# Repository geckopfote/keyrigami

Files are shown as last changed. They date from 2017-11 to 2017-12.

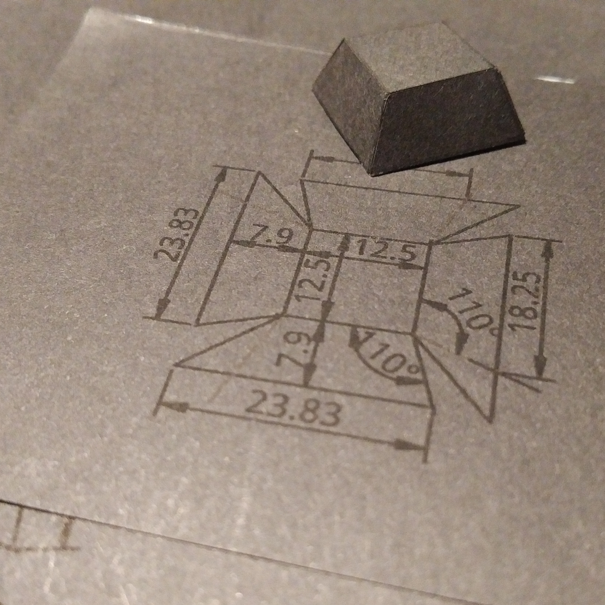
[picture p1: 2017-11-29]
showcase/IMG_20171022_220719_898.jpg

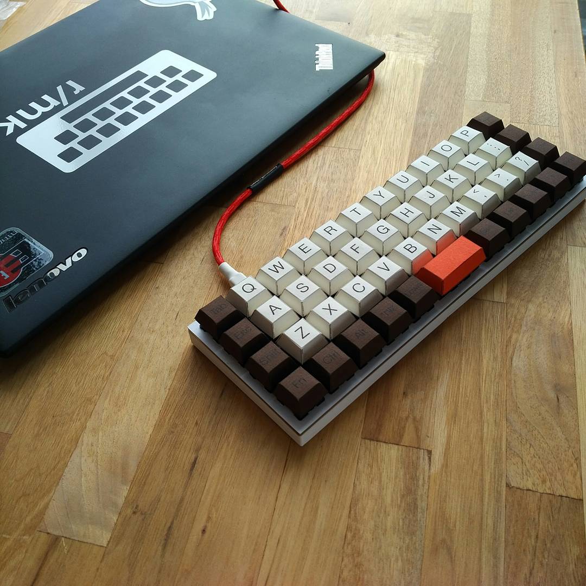
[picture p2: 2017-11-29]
showcase/IMG_20171126_132849_900.jpg

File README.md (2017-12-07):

# keyrigami

Keycaps made from paper

## Table of Contents

1. Keyrigami? What are you talking about?
2. Before you start, or: what you need to make your own paperkeycaps
3. Where to start
4. Credits
5. Links
---

### 1. Keyrigami? What the ...?
Keyrigami is a neologism out of Key(caps) and [Kirigami][1], a variation of Origami. The word keyrigami was first mentioned by u/impudentmortal on [Reddit][2], where I had posted a [picture](../master/showcase/IMG_20171126_0948504.jpg) of my [Origamikeyboard][3].

### 2. Before you start 
You will need only a few things to build your own set of paperkeycaps. First of all you need paper. A weight of 120g-300g should work. Next you need a printer to print the templates of the keycaps and you need also a 3D printer to 3D print the stems of the keycaps. Or at least you should know someone who has a 3D printer and owes you a favor. Furthermore you will need some ordinary office stuff, like glue, scissors and so on. In the wiki, I'll go into details. 

### 3. Where to start
Have a look at the [dsa_family/cad](../master/dsa_family/cad) folder, there are the original keyrigami files from my Origamikeyboard.

### 4. Credits

### 5. Links
- OLKB Keyboards https://olkb.com
- QMK Firmware http://qmk.fm/

---

[1]: https://en.wikipedia.org/wiki/kirigami
[2]: https://www.reddit.com/r/MechanicalKeyboards/comments/7fm4t6/origamikeyboard/dqdek10/
[3]: https://www.reddit.com/r/MechanicalKeyboards/comments/7fm4t6/origamikeyboard/
[4]: https://olkb.com
[5]: http://qmk.fm/

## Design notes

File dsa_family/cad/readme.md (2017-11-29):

This folder contains the different CAD files. I'm using QCad (3.17.3) for the paperkeycaps and FreeCAD (0.17) for the 3D printed parts. Both of them are OpenSource and cross platform. The .dxf-files can also be opened with Inkscape, but it's neither tested nor is it ideal, because the importprocess isn't perfect.

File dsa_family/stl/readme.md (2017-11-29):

This folder contains the .stl file(s), ready for the slicer of your choice. The keybases with a (-)*x*deg in it's filename have a slightly rotated stem, to compensate not straight built-in switches.

---

My slicer settings:

* 3D Printer: Anet A8 Prusa i3
* Slicer Software: Slic3r Prusa Edition

* 0.2mm Nozzle
* Layer Height 0.12mm
* Infill 10%
* Perimeters 1

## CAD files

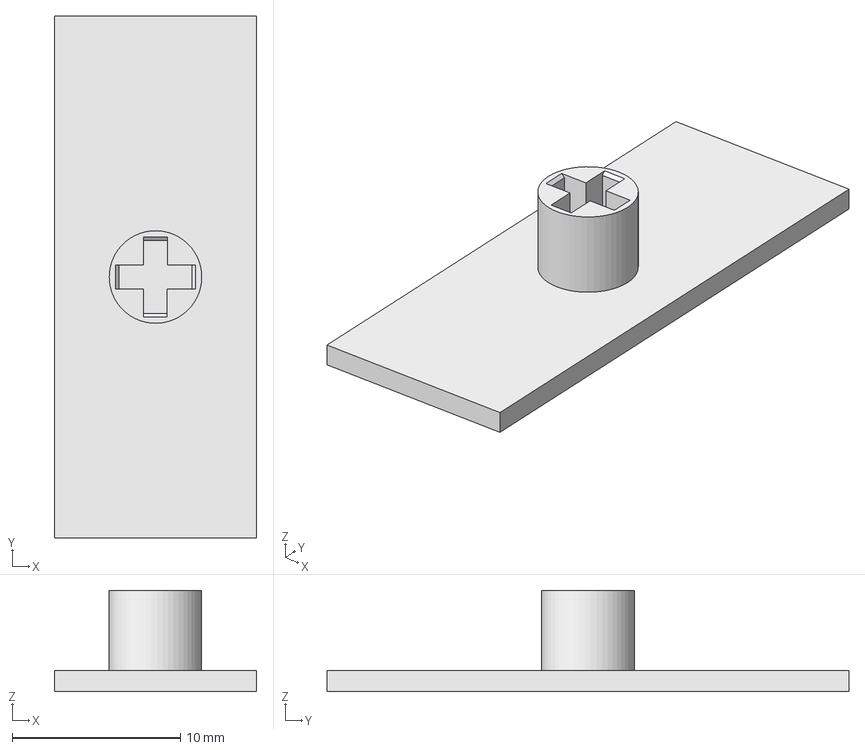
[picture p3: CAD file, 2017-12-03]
dsa_family/cad/okb_keybase_2U_6mm_new.fcstd
12.0 x 31.0 x 6.00 mm

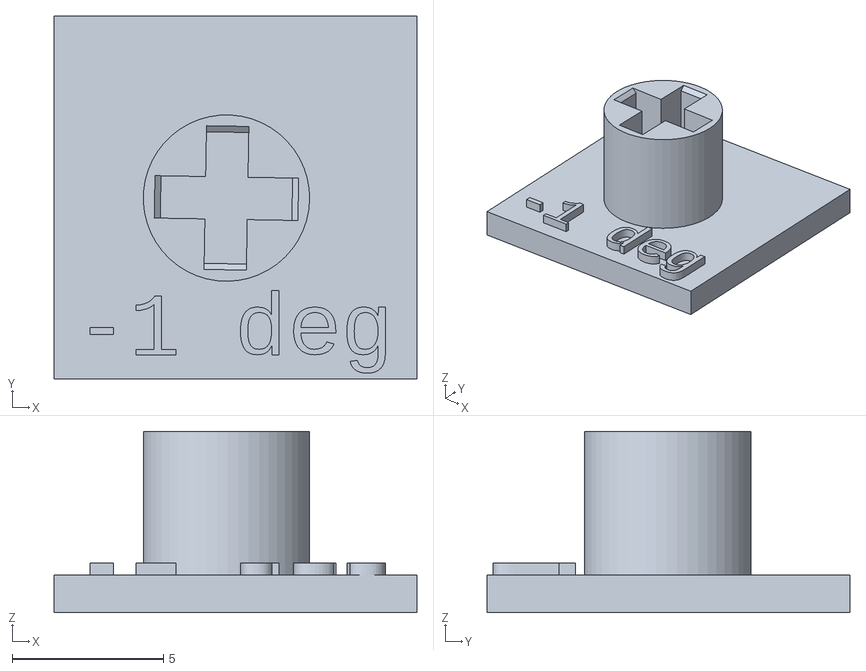
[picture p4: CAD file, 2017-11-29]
dsa_family/stl/okb_keybase_6mm_-1deg.stl
12.0 x 12.0 x 6.00

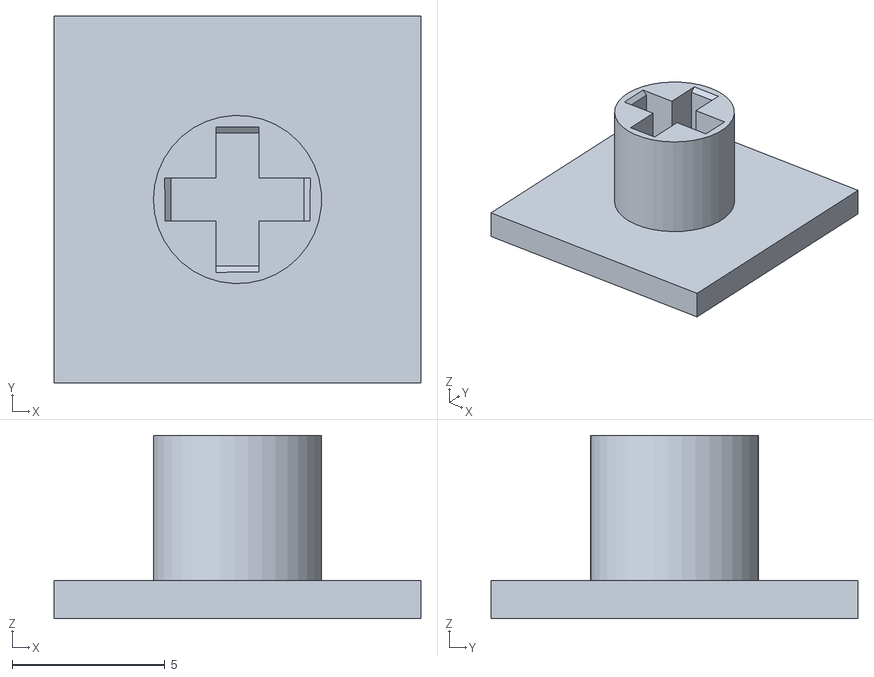
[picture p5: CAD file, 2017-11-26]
dsa_family/stl/okb_keybase_6mm.stl
12.0 x 12.0 x 6.00

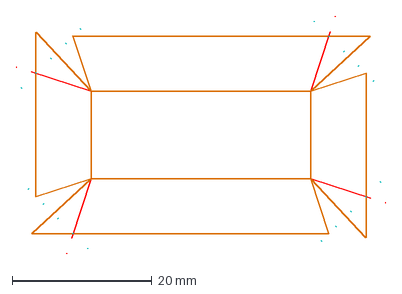
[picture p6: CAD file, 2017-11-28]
dsa_family/cad/keycap2U_single.dxf
53.0 x 34.0 mm

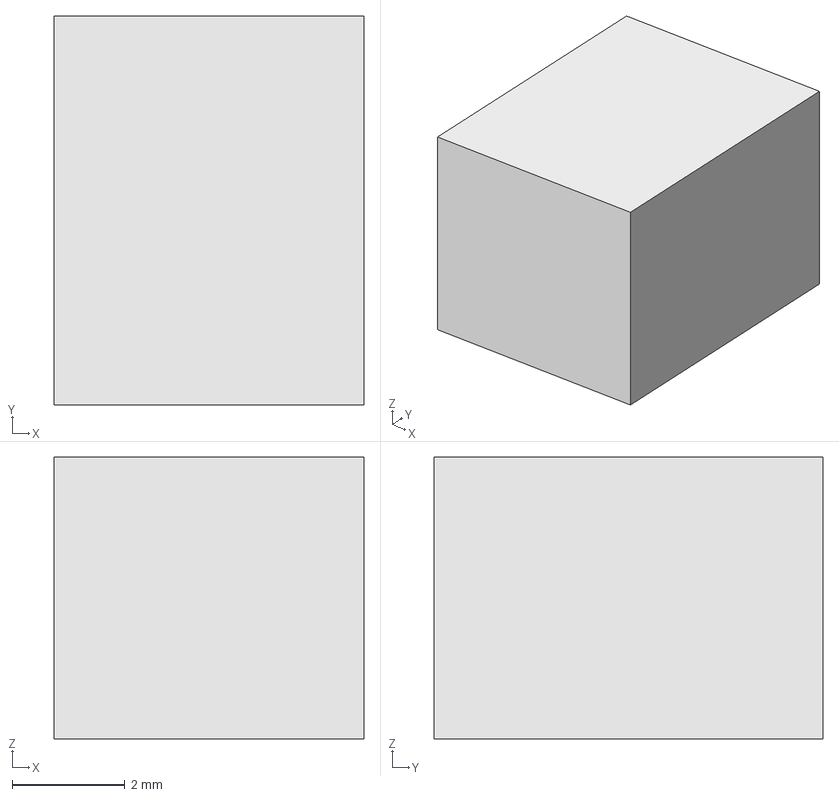
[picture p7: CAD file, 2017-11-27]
dsa_family/cad/okb_keybase_2U_6mm.fcstd
5.50 x 6.90 x 5.00 mm

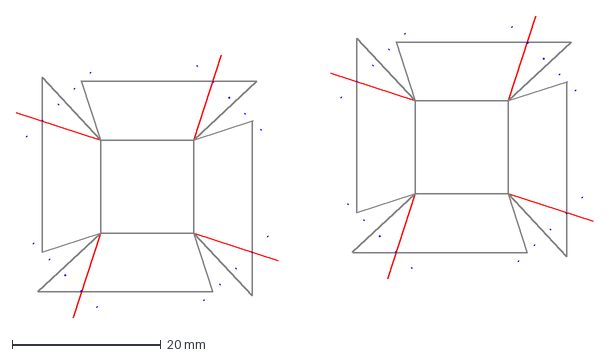
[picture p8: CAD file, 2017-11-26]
dsa_family/cad/keycap1U_special.dxf
77.7 x 40.6 mm

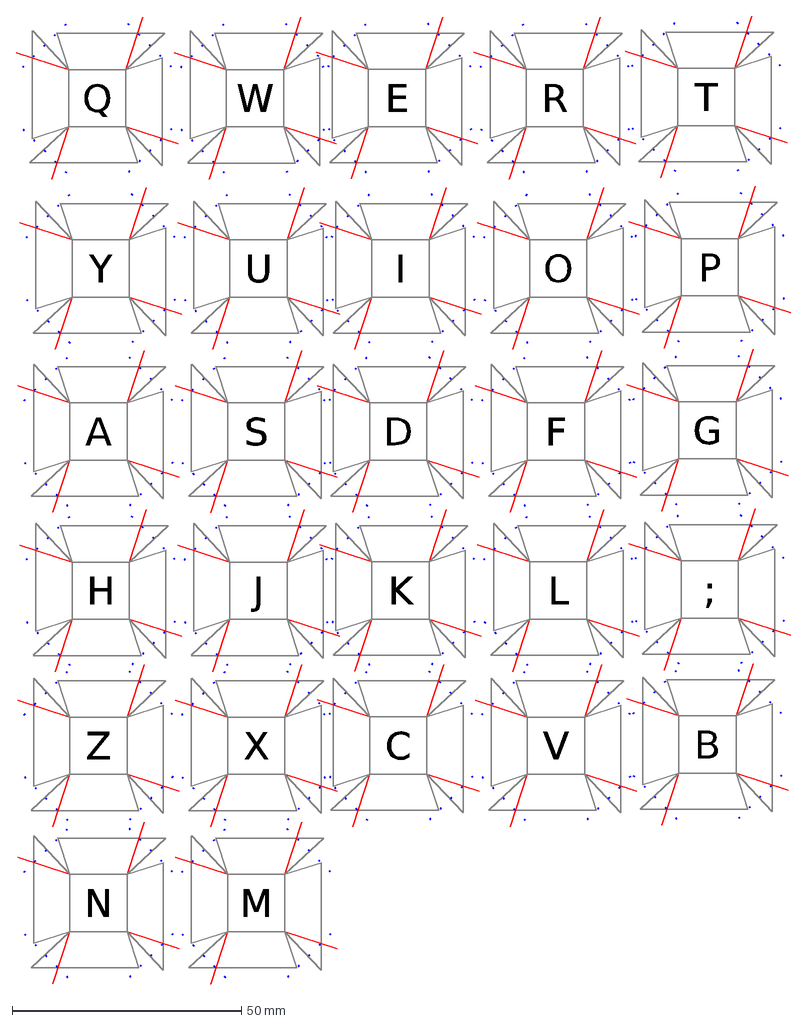
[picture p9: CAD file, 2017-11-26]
dsa_family/cad/keycap1U_alpha.dxf
P
U
O
Y
I
E
R
T
;
J
L
H
K
G
S
F
A
D
M
N
B
X
V
Z
C
W
Q

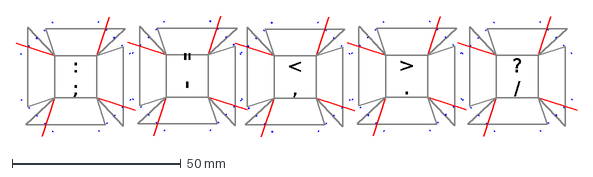
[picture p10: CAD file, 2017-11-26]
dsa_family/cad/keycap1U_non-alphanum.dxf
? /
> .
" '
< ,
: ;

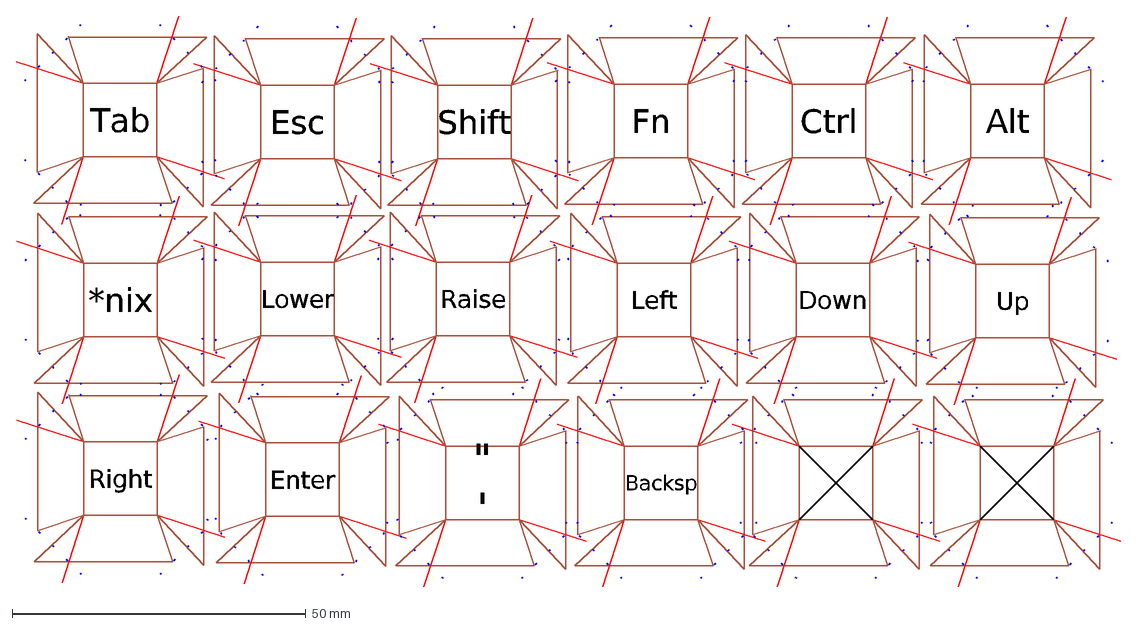
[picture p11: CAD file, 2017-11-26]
dsa_family/cad/keycap1U_function.dxf
Tab
Esc
Shift
Fn
Ctrl
Alt
*nix
Lower
Raise
Left
Down
Up
Right
Enter
Backsp
" '

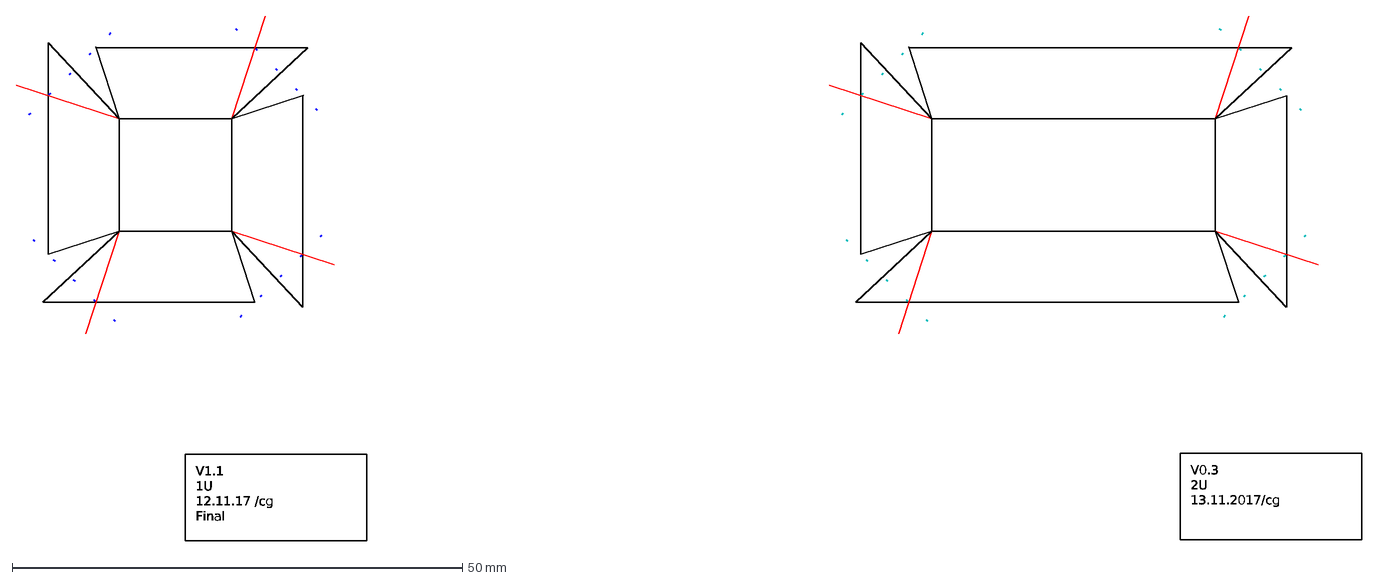
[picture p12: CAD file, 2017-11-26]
dsa_family/cad/keycap1U2U.dxf
V0.3 2U 13.11.2017/cg
V1.1 1U 12.11.17 /cg Final

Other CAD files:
dsa_family/cad/okb_keybase_1U_6mm_-1deg.fcstd
dsa_family/stl/okb_keybase_6mm_-2deg.stl
dsa_family/cad/okb_keybase_1U_6mm_-2deg.fcstd
dsa_family/stl/okb_keybase_6mm_-3deg.stl
dsa_family/cad/okb_keybase_1U_6mm_3deg.fcstd
dsa_family/cad/okb_keybase_1U_6mm.fcstd
dsa_family/cad/okb_keybase_1U_6mm_-3deg.fcstd
dsa_family/cad/okb_keybase_1U_6mm_1deg.fcstd
dsa_family/stl/okb_keybase_2U_6mm_new.stl
dsa_family/stl/okb_keybase_6mm_1deg.stl
dsa_family/stl/okb_keybase_6mm_2deg.stl
dsa_family/stl/okb_keybase_6mm_3deg.stl

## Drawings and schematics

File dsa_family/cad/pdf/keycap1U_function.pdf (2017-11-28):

Tab | Esc | Shift | Fn | Ctrl | Alt

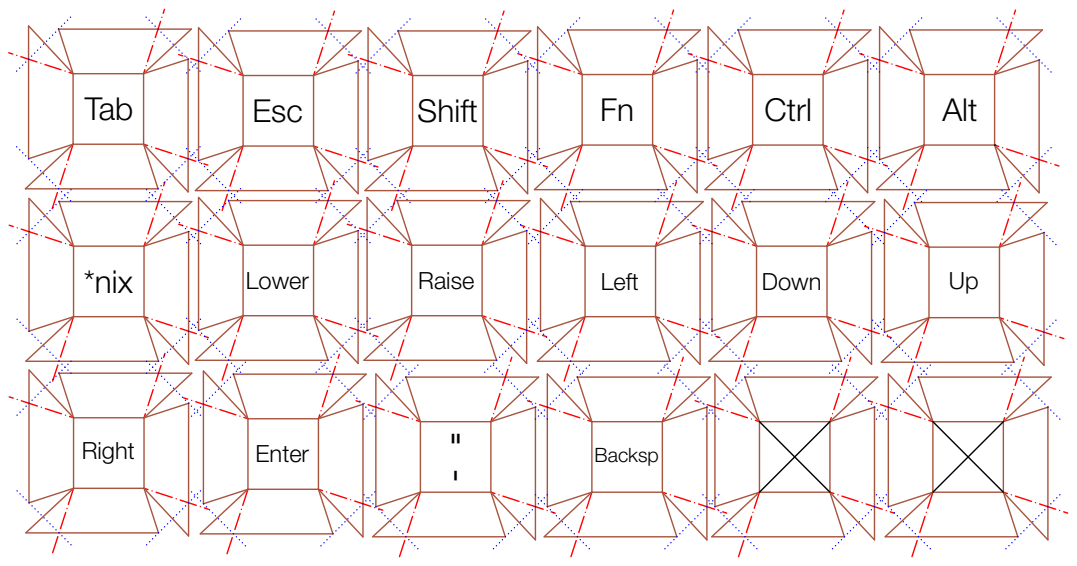
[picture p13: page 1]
*nix; Lower; Raise; Left; Down; Right; Enter; Backsp

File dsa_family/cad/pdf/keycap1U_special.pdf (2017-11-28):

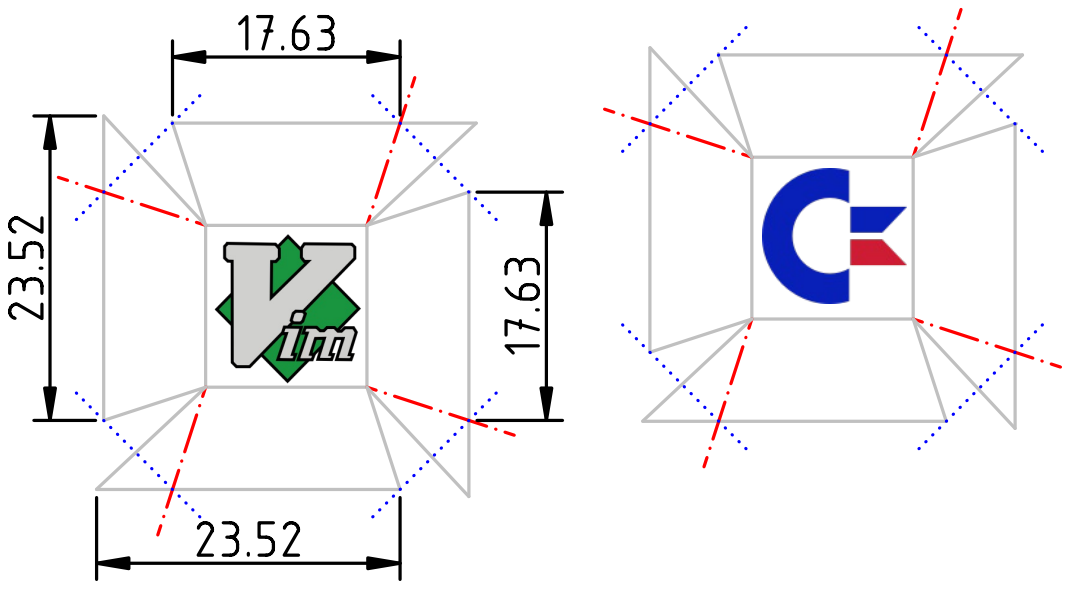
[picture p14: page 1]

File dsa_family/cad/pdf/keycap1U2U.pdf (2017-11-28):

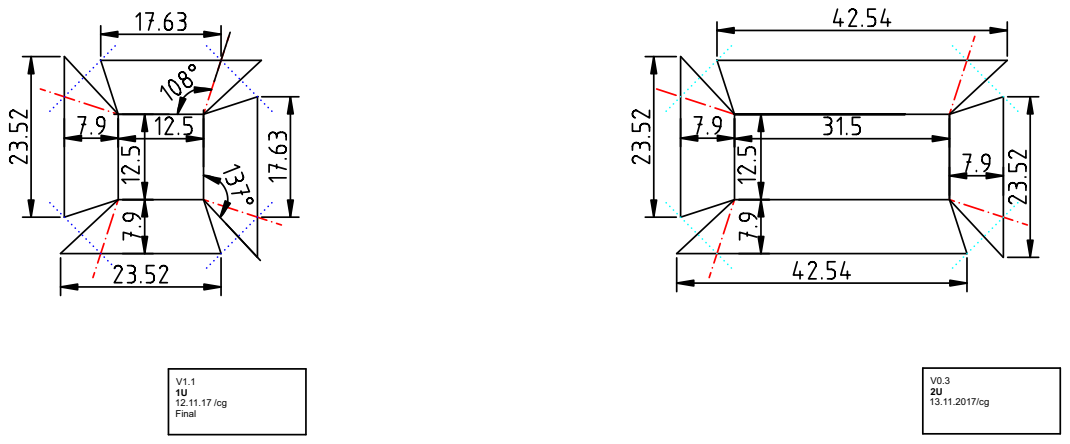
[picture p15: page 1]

V0.3 2U13.11.2017/cg V1.1 1U12.11.17 /cg Final

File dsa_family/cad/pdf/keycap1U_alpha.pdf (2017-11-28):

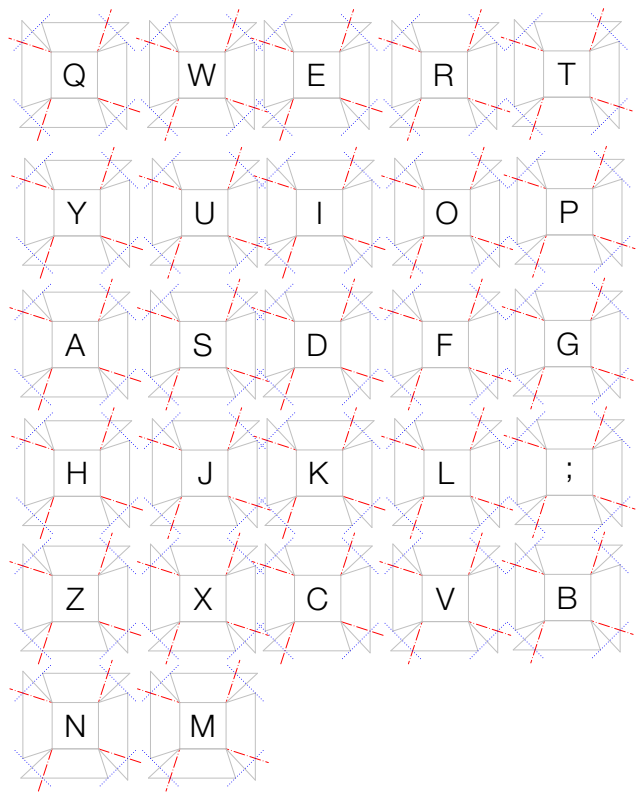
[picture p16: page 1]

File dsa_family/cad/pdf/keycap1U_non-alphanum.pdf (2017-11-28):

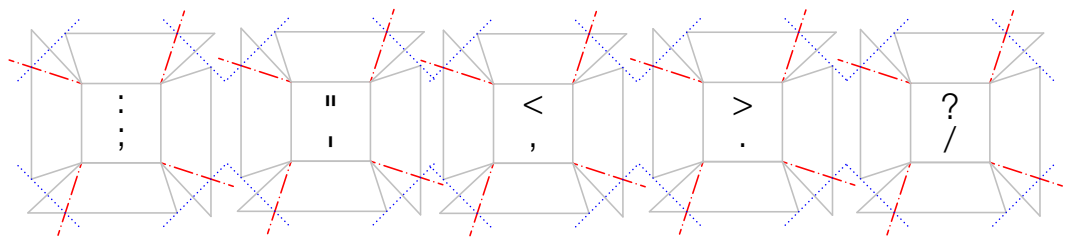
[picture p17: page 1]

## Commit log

2017-11-26 neue Datei: cad/keycap1U2U.dxf
    [keycap1U2U.dxf]
2017-11-26 neue Datei: okb_keybase_6mm.stl
    [okb_keybase_6mm.stl]
2017-11-27 umbenannt: cad/keycap1U2U.dxf -> dsa_family/cad/keycap1U2U.dxf umbenannt: cad/keycap1U_alpha.dxf -> dsa_family/cad/keycap1U_alpha.dxf umbenannt: cad/keycap1U_function.dxf -> dsa_family/cad/keycap1U_f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
    [keycap1U2U.dxf, keycap1U_alpha.dxf, keycap1U_function.dxf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]
2017-11-27 dcs_family/ dsa_family/readme.md sa_family/
    [okb_keybase_2U_6mm.fcstd, okb_keybase_6mm.fcstd]
2017-11-28 neue Datei: keycap2U_single.dxf
    [keycap2U_single.dxf]
2017-11-28 Add files via upload
    Keybase with a rotated stem and cross, for compensation when a switch soldered crooked.
    [okb_keybase_6mm_-3deg.stl]
2017-11-29 neue Datei: okb_keybase_1U_6mm_-3deg.fcstd neue Datei: okb_keybase_1U_6mm_1deg.fcstd neue Datei: okb_keybase_1U_6mm_3deg.fcstd
    [okb_keybase_1U_6mm_-3deg.fcstd, okb_keybase_1U_6mm_1deg.fcstd, okb_keybase_1U_6mm_3deg.fcstd]
2017-11-29 neue Datei: okb_keybase_6mm_-1deg.stl
    [okb_keybase_6mm_-1deg.stl]
2017-11-29 neue Datei: dsa_family/cad/okb_keybase_1U_6mm_-1deg.fcstd geändert: dsa_family/stl/okb_keybase_6mm_-1deg.stl
    [okb_keybase_1U_6mm_-1deg.fcstd]
2017-11-30 Delete okb_keybase_1U_6mm_-3deg.fcstd
    duplicate
    [okb_keybase_1U_6mm_-3deg.fcstd]
2017-11-30 Delete okb_keybase_1U_6mm_1deg.fcstd
    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
    [okb_keybase_1U_6mm_1deg.fcstd]
2017-11-30 Delete okb_keybase_1U_6mm_3deg.fcstd
    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
    [okb_keybase_1U_6mm_3deg.fcstd]
